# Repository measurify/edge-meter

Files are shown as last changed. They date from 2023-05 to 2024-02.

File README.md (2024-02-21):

# Measurify Edge Meter

Edge Measurer is a board based on the [Arduino Nano BLE Sense](https://store.arduino.cc/products/nano-33-ble-sense-rev2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). The board is enhanced with a battery support as in the following figures:

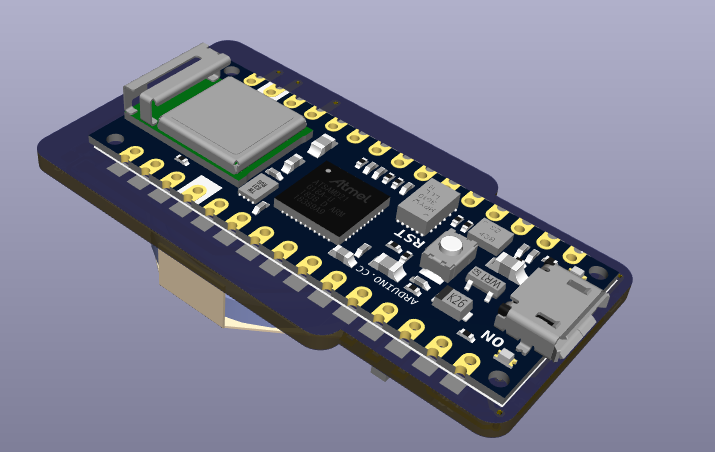
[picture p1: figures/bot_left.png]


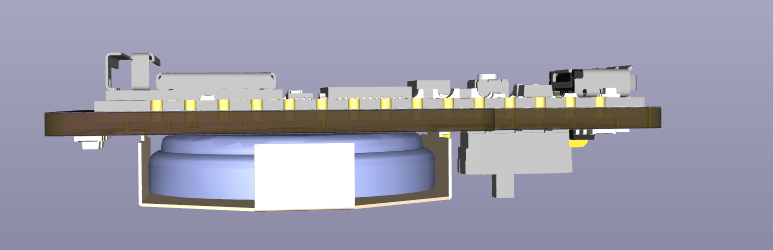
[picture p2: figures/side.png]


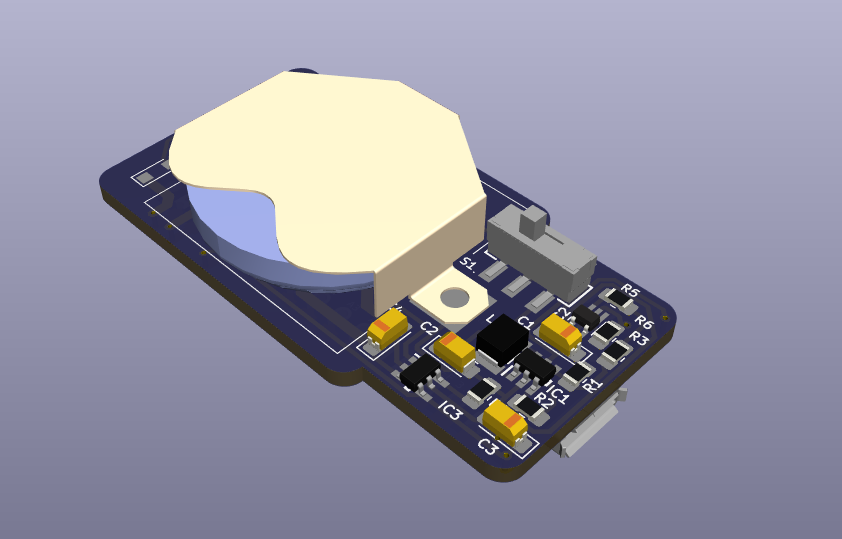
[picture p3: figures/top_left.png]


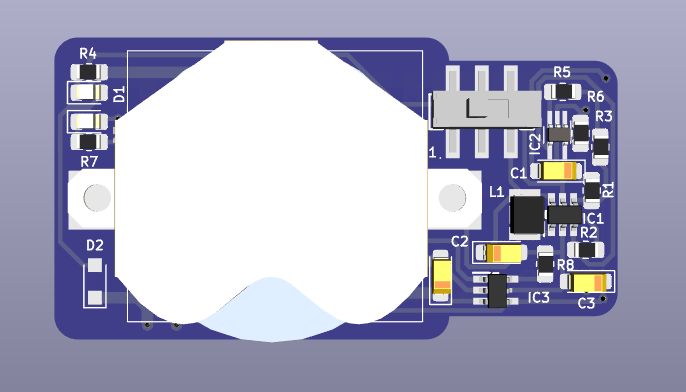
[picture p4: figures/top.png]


EdgeMeter acquires values from sensors on the Arduino device and exposes the collected data using the on-board BLE connectivity. It provides IMU values (accelerometer, gyroscope and magnetometer), environmental values (proximity, temperature, humidity, pressure and ambient light) and orientation (heading, pitch, roll) as BLE characteristics. The sampling period can be decided by the connected client, the default value is 250 msec.

Two versions of arduino are supported: Change the name in the first line of the file edge-meter.ino as NANO_V1 for **Arduino Nano 33 BLE Sense** or NANO_V2 for **Arduino Nano 33 BLE Sense REV2**.

Folder node-client contains an example of client application developed in NodeJS.

Current version of BLE only allows a maximum of 20 bytes for each message. To send the array of IMU and ENV values we had to convert each value to 16-bit signed integer (int16_t). Sensor resolution is 16 bit so no information is lost. Values are multiplied to a coefficient described below.

The BLE local name is **Mesurify-Meter** and it exposes a single BLE service (UUID: 8e7c2dae-0000-4b0d-b516-f525649c49ca) featuring the following characteristics:

## Sampling Period Characteristic

- UUID: 8e7c2dae-0001-4b0d-b516-f525649c49ca
- Properties: read and write
- Data format: 16-bit unsigned integer
- Values: sampling period in msec

## IMU Characteristic

- UUID: 8e7c2dae-0002-4b0d-b516-f525649c49ca
- Properties: notify
- Original format: array of 9 float
- Data format: array of 9 signed int 16 bit
- Values: acceleration [G] * 8192 , angular velocity [dps] * 16.384 , and magnetic field [uT] * 81.92

## Environment Characteristic

- UUID: 8e7c2dae-0003-4b0d-b516-f525649c49ca
- Properties: notify
- Original format: 3 float and 5 int
- Data format: array of 8 signed int 16 bit
- Values: proximity [0 close, 255 far], temperature [C] * 100 , humidity [%] * 100 , pressure [kPA] * 100 , ambient light [0 dark] and color [RGB]

## Orientation Characteristic

- UUID: 8e7c2dae-0004-4b0d-b516-f525649c49ca
- Properties: notify
- Data format: array of 3 float
- Values: heading [degree], pitch [dpdegrees], and roll [degree]

# Citation
If you find the project helpful, please consider citing our paper:

[1] M. Fresta, A. Dabbous, F. Bellotti, A. Capello, L. Lazzaroni, A. Pighetti, R. Berta.
 **Low-Cost, Edge-Cloud, End-to-End System Architecture for Human Activity Data Collection**. Applications in Electronics Pervading Industry, Environment and Society. ApplePies 2023. Lecture Notes in Electrical Engineering, vol 1110. Springer, Cham. [LINK](https://doi.org/10.1007/978-3-031-48121-5_64)

[2] A. Dabbous, M. Fresta, F. Bellotti, R. Berta. **Neural Architecture for Tennis Shot Classification on Embedded System**. Applications in Electronics Pervading Industry, Environment and Society. ApplePies 2023. Lecture Notes in Electrical Engineering, vol 1110. Springer, Cham. [LINK](https://doi.org/10.1007/978-3-031-48121-5_14)

[3] A. Dabbous, M. Fresta, F. Bellotti, R. Berta. **Arduino Nano-based System for Tennis Shot Classification**. 54th Annual Meeting of the Italian Electronics Society, SIE 2023, Noto, Italy, 2023. [LINK](https://doi.org/10.1007/978-3-031-48711-8_43)

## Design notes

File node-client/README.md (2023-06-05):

# Measurify Collector

Measurify Collector is Node.js module for the Measurify Meter board. The module makes easy to listen to data from one or more sensors from the Meter board using a BLE connection and send the collected data to a Measurify server.

In oder to use the module, you have to import it, define the charactercist you are interested in and instantiate a new Connector object:

'''
const Connector = require('./connector.js')
const options = { enable: ['imu', 'env'] }
const connector = new Connector(options);
'''

The you have to connect to the Meter and waiting for it:

'''
await connector.connect();
'''

Finaly you have to specify the call backs for the most important events: connection, error and disconnection. In particular, after connetion you can specify callcacks for the different characteristics value changes notification:

connector.on('connected', id => {
	
	connector.on('imu', data => { 
	    console.log('IMU values:', data) 
	});

	connector.on('env', data => { 
		console.log('Environment values:', data); 
	});
});

connector.on('error', async err => { 
	console.error(err.message); 
});

connector.on('disconnected', async id => { 
	console.log(`Disconnected`) 
});
'''

You can control also the rate ar which the Meter will polling data from sensor:

'''
connector.write('timing', 5000);
'''

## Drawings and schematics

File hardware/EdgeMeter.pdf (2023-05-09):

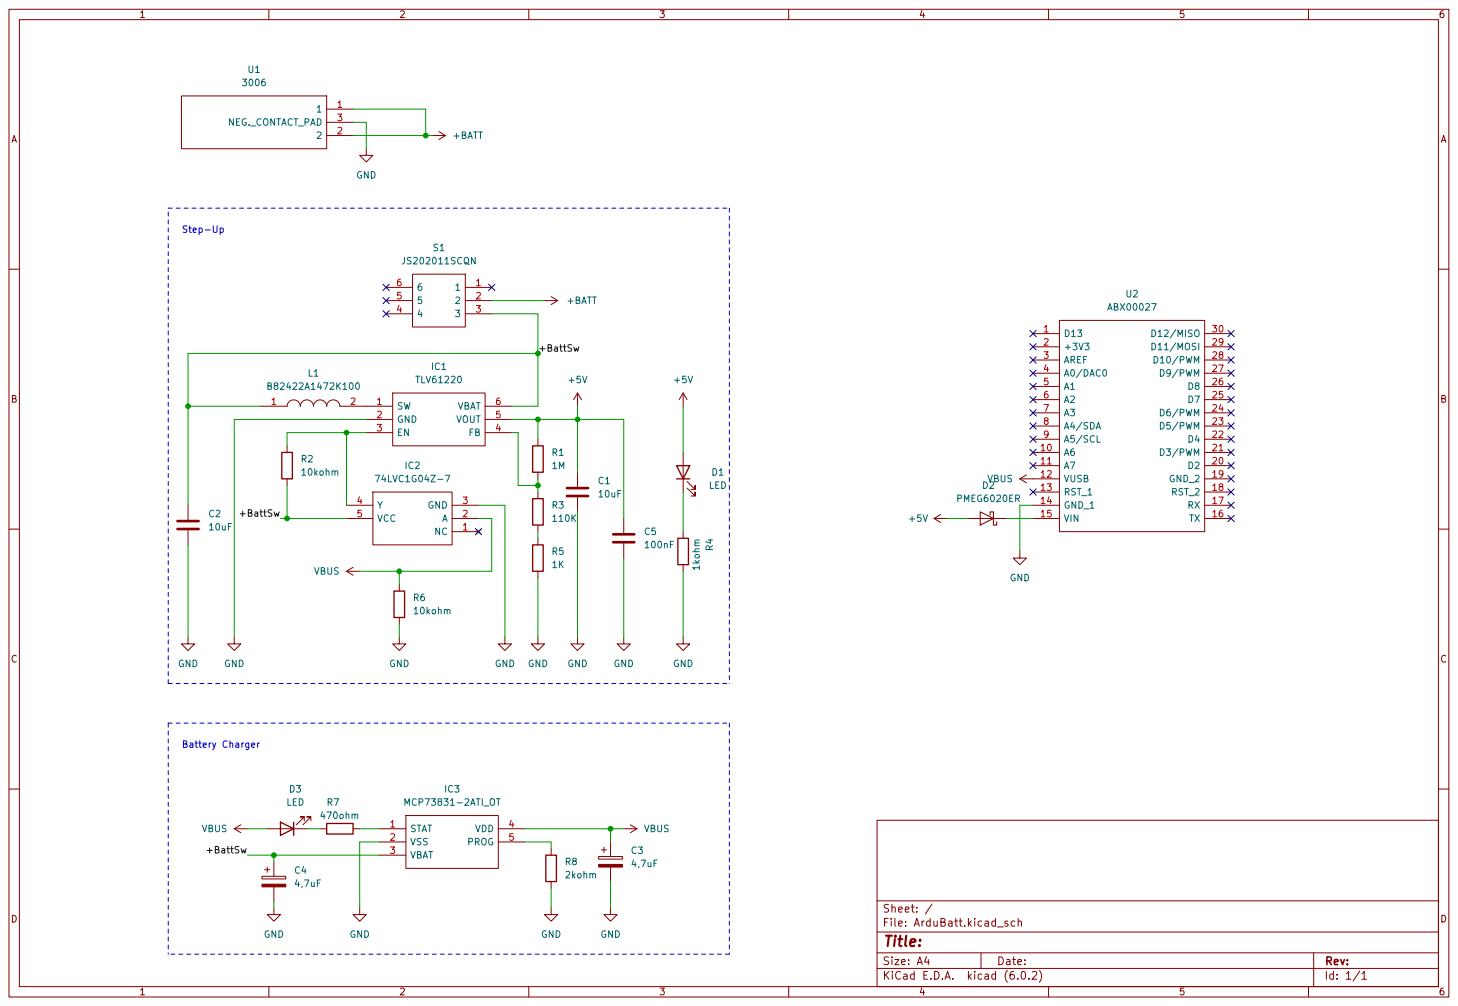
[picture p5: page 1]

File: ArduBatt.kicad_sch Sheet: / GND

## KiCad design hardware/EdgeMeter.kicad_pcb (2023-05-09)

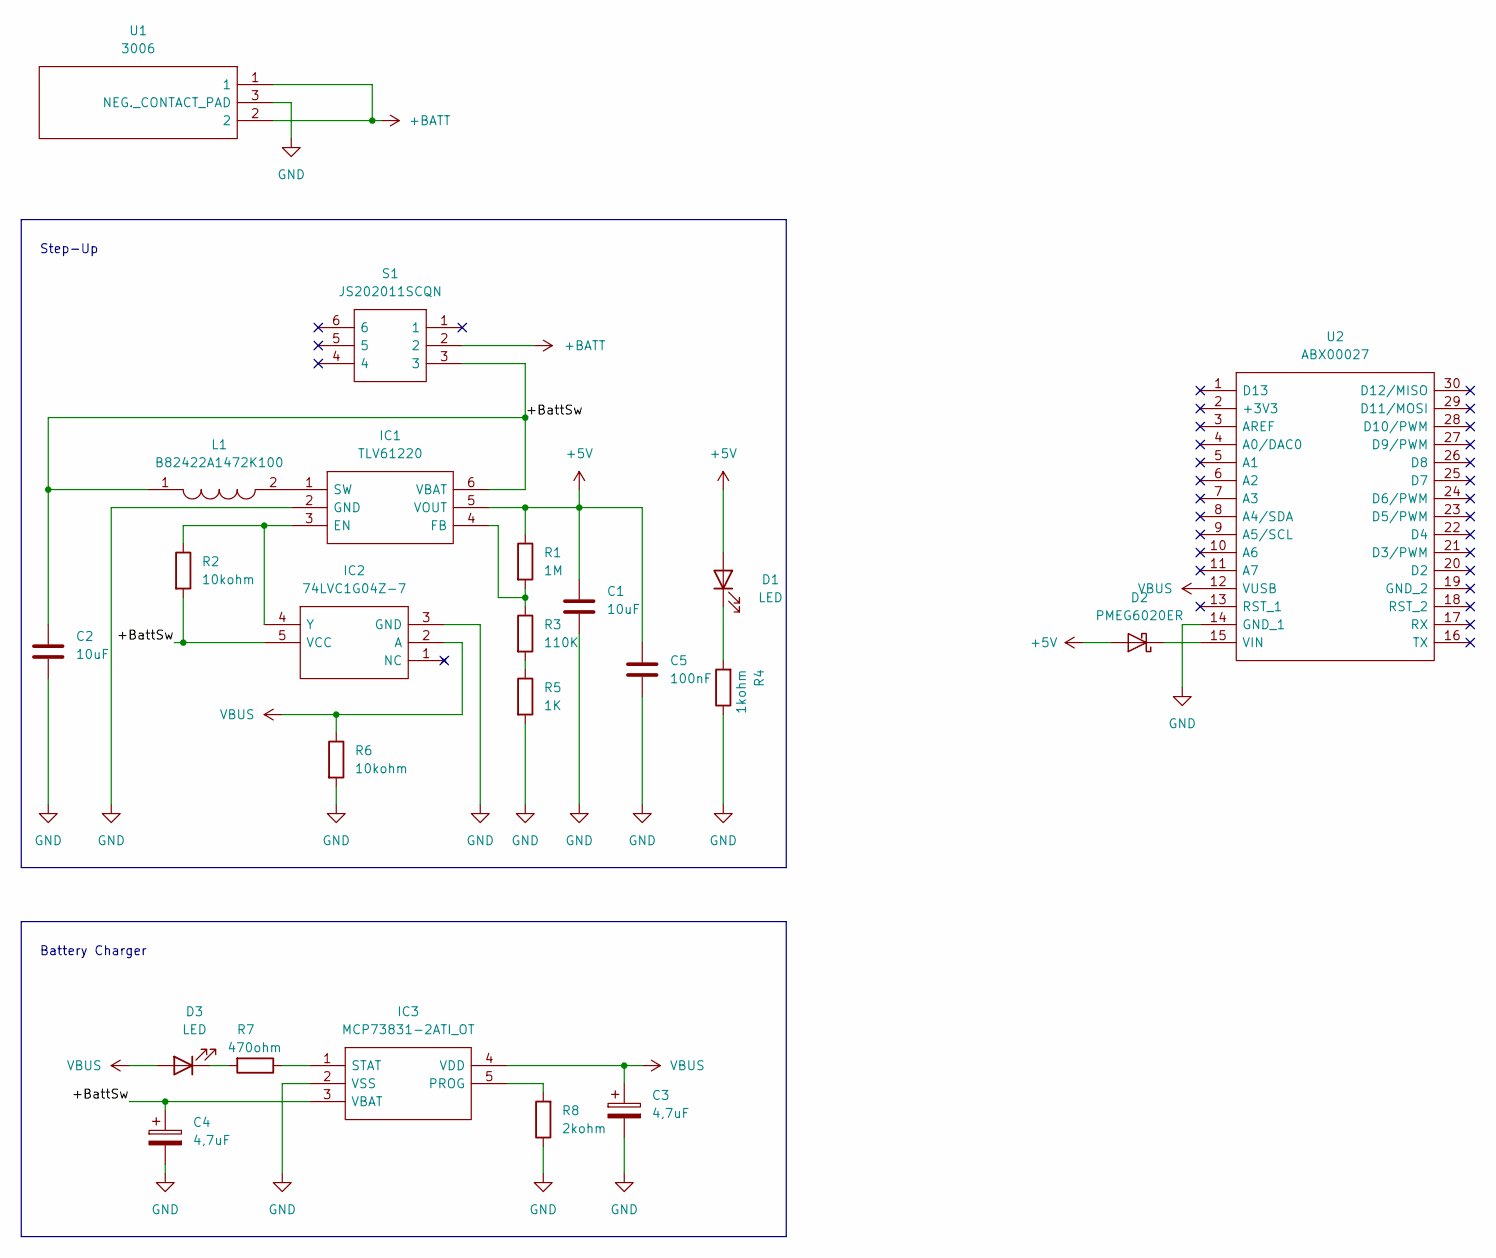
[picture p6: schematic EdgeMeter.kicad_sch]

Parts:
C1, C2: 10uF; CP_EIA-3216-18_Kemet-A_Pad1.58x1.35mm_HandSolder
C3, C4: 4,7uF; CP_EIA-3216-18_Kemet-A_Pad1.58x1.35mm_HandSolder
C5: 100nF; C_0805_2012Metric_Pad1.18x1.45mm_HandSolder
D1, D3: LED; LED_0805_2012Metric_Pad1.15x1.40mm_HandSolder
D2: PMEG6020ER; D_SOD-128
IC1: TLV61220; SOT95P280X145-6N; Manufacturer_Part_Number TLV61220
IC2: 74LVC1G04Z-7; SOT-353_SC-70-5_Handsoldering; Manufacturer_Part_Number 74LVC1G04Z-7; Mouser Part Number 621-74LVC1G04Z-7
IC3: MCP73831-2ATI_OT; SOT95P270X145-5N; Manufacturer_Part_Number MCP73831-2ATI/OT
L1: B82422A1472K100; INDC3225X210N; Manufacturer_Part_Number B82422A1472K100; Mouser Part Number 871-B82422A1472K100
R1: 1M; R_0805_2012Metric_Pad1.20x1.40mm_HandSolder
R2, R6: 10kohm; R_0805_2012Metric_Pad1.20x1.40mm_HandSolder
R3: 110K; R_0805_2012Metric_Pad1.20x1.40mm_HandSolder
R4: 1kohm; R_0805_2012Metric_Pad1.20x1.40mm_HandSolder
R5: 1K; R_0805_2012Metric_Pad1.20x1.40mm_HandSolder
R7: 470ohm; R_0805_2012Metric_Pad1.20x1.40mm_HandSolder
R8: 2kohm; R_0805_2012Metric_Pad1.20x1.40mm_HandSolder
S1: JS202011SCQN; Manufacturer_Part_Number JS202011SCQN; Mouser Part Number 611-JS202011SCQN
U1: 3006; Manufacturer_Part_Number 3006; Mouser Part Number 534-3006
U2: ABX00027; Manufacturer_Part_Number ABX00027; Mouser Part Number 782-ABX00027

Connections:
+5V: C1.1, C5.1, D1.2 (A), D2.2 (A), IC1.5 (VOUT), R1.1
+BATT: S1.2, U1.1, U1.2
/+BattSw: C2.1, C4.1, IC1.6 (VBAT), IC2.5 (VCC), IC3.3 (VBAT), L1.1, R2.2, S1.3
GND: C1.2, C2.2, C3.2, C4.2, C5.2, IC1.2 (GND), IC2.3 (GND), IC3.2 (VSS), R4.1, R5.2, R6.2, R8.1, U1.3 (NEG._CONTACT_PAD), U2.14 (GND_1)
unnamed: D1.1 (K), R4.2
unnamed: D2.1 (K), U2.15 (VIN)
unnamed: D3.1 (K), R7.2
unnamed: IC1.1 (SW), L1.2
unnamed: IC1.3 (EN), IC2.4 (Y), R2.1
unnamed: IC1.4 (FB), R1.2, R3.1
unnamed: IC3.1 (STAT), R7.1
unnamed: IC3.5 (PROG), R8.2
unnamed: R3.2, R5.1
VBUS: C3.1, D3.2 (A), IC2.2 (A), IC3.4 (VDD), R6.1, U2.12 (VUSB)

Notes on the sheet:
Battery Charger
Step-Up

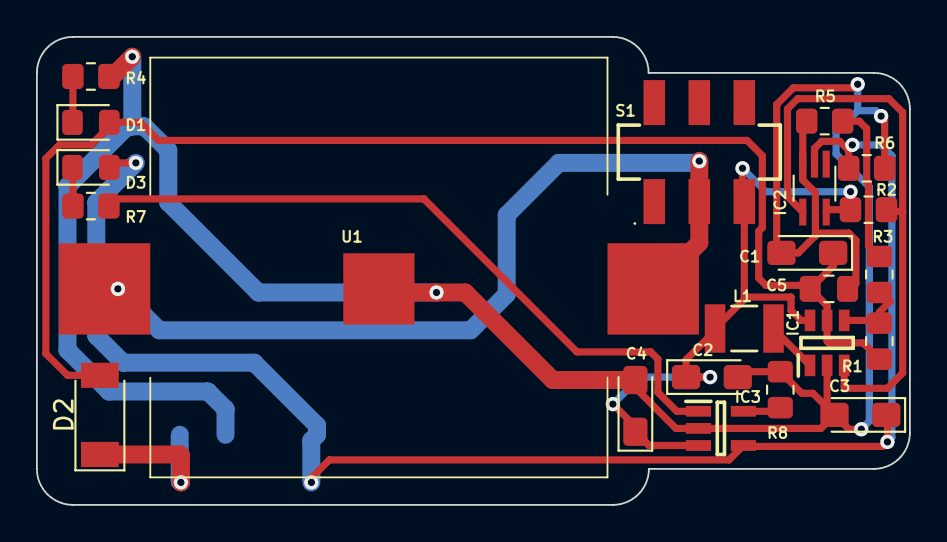
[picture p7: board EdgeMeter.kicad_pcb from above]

Board: 2 copper layers, 48.5 x 26.0 mm, 23 parts (1 on the bottom side), 14 nets.

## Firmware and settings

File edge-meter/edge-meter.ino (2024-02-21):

#define NANO_V1 //NANO_V2

#include <Arduino_APDS9960.h>
#include <Arduino_LPS22HB.h>

#ifdef NANO_V1
#include <Arduino_HTS221.h>
#include <Arduino_LSM9DS1.h>
#endif

#ifdef NANO_V2
#include <Arduino_HS300x.h>
#include <Arduino_BMI270_BMM150.h>
#endif 

#include <MadgwickAHRS.h>
#include <ArduinoBLE.h>

#define ACC_MULTIPLIER 8192
#define GYR_MULTIPLIER 16.384
#define MAG_MULTIPLIER 81.92
#define TEMP_MULTIPLIER 100
#define HUM_MULTIPLIER 100
#define PRES_MULTIPLIER 100


String name = "Mesurify-Meter";

Madgwick filter;

const char* service_uuid = "8e7c2dae-0000-4b0d-b516-f525649c49ca";
const char* sampling_period_uuid = "8e7c2dae-0001-4b0d-b516-f525649c49ca";
const char* imu_uuid = "8e7c2dae-0002-4b0d-b516-f525649c49ca";
const char* environment_uuid = "8e7c2dae-0003-4b0d-b516-f525649c49ca";
const char* orientation_uuid = "8e7c2dae-0004-4b0d-b516-f525649c49ca";

BLEService service(service_uuid);

// Loop delay
int sampling_period = 100;
int heartbit_period = 5000;
unsigned long sampling_previousMillis = 0;
unsigned long heartbit_previousMillis = 0;
BLECharacteristic samplingPeriodCharacteristic(sampling_period_uuid,  BLEWrite | BLERead, sizeof(int));

// IMU: 9 ints G, degress per second, uT (G*8192,degrees per second*16.384,uT*81.92)
float acceleration[3];
float angular_speed[3];
float magnetic_field[3];
BLECharacteristic imuCharacteristic(imu_uuid, BLENotify, 9 * sizeof(int16_t)); 

// Environment: proximity, temperature, humidity, pressure, light, r, g, b  
int16_t proximityInt16;
int16_t temperatureInt16;
int16_t humidityInt16;
int16_t pressureInt16;
int light;
int red, green, blue;
int16_t lightInt16;
int16_t redInt16, greenInt16, blueInt16;
BLECharacteristic environmentCharacteristic(environment_uuid, BLENotify, 8 * sizeof(int16_t));

// Orientation: 3 floats degress
float heading;
float pitch;
float roll;
BLECharacteristic orientationCharacteristic(orientation_uuid, BLENotify, 3 * sizeof(float)); 

void init_sensors(void){
  while(!APDS.begin()) { Serial.println("Error, APDS"); delay(500); };

  #ifdef NANO_V1
  while(!HTS.begin()) { Serial.println("Error, HTS"); delay(500); };
  #endif
  
  #ifdef NANO_V2
  while(!HS300x.begin()) { Serial.println("Error, HTS"); delay(500); };
  #endif
  
  while(!BARO.begin()) { Serial.println("Error, BARO"); delay(500); };
  while(!IMU.begin()) { Serial.println("Error, IMU"); delay(500); };
}

void init_BLE(){
  while(!BLE.begin()) { Serial.println("Error, BLE"); delay(500); };

  String address = BLE.address();

  BLE.setLocalName(name.c_str());
  BLE.setDeviceName(name.c_str());
  BLE.setAdvertisedService(service); 
   
  service.addCharacteristic(imuCharacteristic);
  service.addCharacteristic(environmentCharacteristic);
  service.addCharacteristic(orientationCharacteristic);

  samplingPeriodCharacteristic.setEventHandler(BLEWritten, onSamplingPeriodCharacteristicWrite);
  service.addCharacteristic(samplingPeriodCharacteristic);
  
  BLE.addService(service);
  BLE.advertise();
}
void initFilter(){
  filter.begin(1000/sampling_period);
}

void setup() {
  Serial.begin(9600);

  Serial.println("Init sensors...");  
  init_sensors();
  
  Serial.println("Init BLE...");  
  init_BLE();

  Serial.println("Init Filter...");  
  initFilter();

  Serial.println("Start loop...");  
}

void manageRawValues() {
  if (IMU.accelerationAvailable()) {
    float x, y, z;
    IMU.readAcceleration(x, y, z);
    acceleration[0] = x;
    acceleration[1] = y;
    acceleration[2] = z;
  }
  
  if (IMU.gyroscopeAvailable()) {
    float x, y, z;
    IMU.readGyroscope(x, y, z);
    angular_speed[0] = x;
    angular_speed[1] = y;
    angular_speed[2] = z;
  }

  if (IMU.magneticFieldAvailable()) {
    float x, y, z;
    IMU.readMagneticField(x, y, z);
    magnetic_field[0] = x;
    magnetic_field[1] = y;
    magnetic_field[2] = z;
  }
}

void manageIMU() {
  int16_t imu[9] = { (int16_t)round(acceleration[0]*ACC_MULTIPLIER), (int16_t)round(acceleration[1]*ACC_MULTIPLIER), (int16_t)round(acceleration[2]*ACC_MULTIPLIER), 
                   (int16_t)round(angular_speed[0]*GYR_MULTIPLIER), (int16_t)round(angular_speed[1]*GYR_MULTIPLIER), (int16_t)round(angular_speed[2]*GYR_MULTIPLIER),
                   (int16_t)round(magnetic_field[0]*MAG_MULTIPLIER), (int16_t)round(magnetic_field[1]*MAG_MULTIPLIER), (int16_t)round(magnetic_field[2]*MAG_MULTIPLIER) 
                 };
  imuCharacteristic.writeValue(imu, sizeof(imu));
} 

void manageOrientation(){
  filter.update(angular_speed[0], angular_speed[1], angular_speed[2],
                acceleration[0], acceleration[1], acceleration[2],
                magnetic_field[0], magnetic_field[1], magnetic_field[2]);

  heading = filter.getYawRadians();
  pitch = filter.getPitchRadians();
  roll = filter.getRollRadians();

  float orientation[3] = { heading, pitch, roll };
  orientationCharacteristic.writeValue(orientation, sizeof(orientation));
}

void manageEnvironment() {
  if (APDS.proximityAvailable()) { proximityInt16 = (int16_t)round(APDS.readProximity()); }
  
  #ifdef NANO_V1
  temperatureInt16 = (int16_t)round(HTS.readTemperature()*TEMP_MULTIPLIER); 
  humidityInt16 = (int16_t)round(HTS.readHumidity()*HUM_MULTIPLIER); 
  #endif

  #ifdef NANO_V2
  temperatureInt16 = (int16_t)round(HS300x.readTemperature()*TEMP_MULTIPLIER);
  humidityInt16 = (int16_t)round(HS300x.readHumidity()*HUM_MULTIPLIER);
  #endif

  pressureInt16 = (int16_t)round(BARO.readPressure()*PRES_MULTIPLIER);
  if (APDS.colorAvailable()) { APDS.readColor(red, green, blue, light); 
    redInt16 = (int16_t)round(red);
    greenInt16 = (int16_t)round(green);
    blueInt16 = (int16_t)round(blue);
    lightInt16 = (int16_t)round(light);
   }

  int16_t environment[8] = { proximityInt16, temperatureInt16, humidityInt16, pressureInt16, lightInt16, redInt16, greenInt16, blueInt16 };
  environmentCharacteristic.writeValue(environment, sizeof(environment));
} 

void onSamplingPeriodCharacteristicWrite(BLEDevice central, BLECharacteristic characteristic) {
  sampling_period = word(samplingPeriodCharacteristic[0], samplingPeriodCharacteristic[1]);
  Serial.print("Sampling period change: "); 
  Serial.print(sampling_period);
  Serial.println(" ms"); 
}

void heartbit() {
  if (millis() - heartbit_previousMillis >= heartbit_period) {
      if (BLE.connected()) {
        Serial.print("BLE client connected (");
        Serial.print(BLE.address());
        Serial.println(")...");
        Serial.print(" - Sampling period: ");
        Serial.println(sampling_period);
        if (imuCharacteristic.subscribed()) Serial.println(" - IMU subscribed");
        if (environmentCharacteristic.subscribed()) Serial.println(" - Environment subscribed");
        if (orientationCharacteristic.subscribed()) Serial.println(" - Orientation subscribed");
      }
      else {
        Serial.println("No BLE client connected...");
      }
      heartbit_previousMillis = millis();
    }
}

void loop() {
  heartbit();
  if (BLE.connected()) {
    if (millis() - sampling_previousMillis >= sampling_period) {
      if (imuCharacteristic.subscribed() || orientationCharacteristic.subscribed()) { manageRawValues(); }
      if (imuCharacteristic.subscribed()) { manageIMU(); }
      if (environmentCharacteristic.subscribed()) { manageEnvironment(); }
      if (orientationCharacteristic.subscribed()) { manageOrientation(); }
      sampling_previousMillis = millis();
    }
  } 
}
